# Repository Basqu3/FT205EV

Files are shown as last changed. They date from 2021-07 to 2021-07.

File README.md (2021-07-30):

# **FT205EV**

### Introductory Information:
	The FT205EV Sensor is an ultrasonic wind sensor. It utilizes known properties of sound to measure wind speed,
	wind direction in relation to the onboard compass, and temperature. This project provides a method to mount the sensor, PCB and required external battery on a DJI Inspire. 
	File List:
	PCB (not including Arduino, Micro-SD card holder or Micro-SD card)
	STL files for 3D printing (PLA)
	.INO file for Arduino

	The PCB .zip file folder is an EasyEDA format. It contains all required files, and a BOM parts list. 
		Some soldering skills are required to assemble the PCB. Note that the led-resistor combos (POWER and DATA) are optional.
		The POWER area can remain empty; DATA requires a solder bridge over both resistor and led footprints. 

	The STL 3D printing files are optimized for a 2S 7.4V LiPo Battery. The sensor mount screws onto the sensor; and twists into the Inspire Camera lock. 
		The enclosure box hooks on the thorn of the gimble, and clicks into place. 

	The .INO file needs to be uploaded to the Arduino before use with the sensor. It utilizes <SPI.h>, <SD.h>, <Wire.h>, and "RTClib.h" libraries. 

### Sensor Overview:
	The FT205EV sensor requires a DC voltage across the range of 6-30 V. The PCB will handle voltage between 6-8V. 
	If a different power source (not the 7.4V LiPo) is desired, voltage regulation needs to be included. 
	The Sensor uses Serial ASCII communication. It has 3 protocol options: RS422, RS485 and UART. This system utilizes UART. 
	Any connection to a pc can be done with the included RS485 cable. The PC will require a serial interface. This project recommends TeraTerm. 
	TeraTerm requires some familiarity to serial communications to use. Power the RS485 cable with a benchtop power supply (within 6-30V) and plug the USB into the PC. 
	Open TeraTerm and select the USB COM port in the serial dropdown. The Sensor requires CR+LF line endings so open SETUP>TERMINAL in the TeraTerm window. Change the New-Line      options from CR to CR+LF. 
	Optionally check the Local Echo box to see user input. Before any communications are made; the sensor needs to be set into RS485 mode and the continuous update turned off. Do that using these commands:
		$01,CUD*//  
		$01,CI8*//
	After these commands are entered; the sensor should be able to communicate with the PC. Either open the ACU-VIS included software or send commands through TeraTerm to ensure connection. 
	Check the Sensor User Manual to see full list of commands.

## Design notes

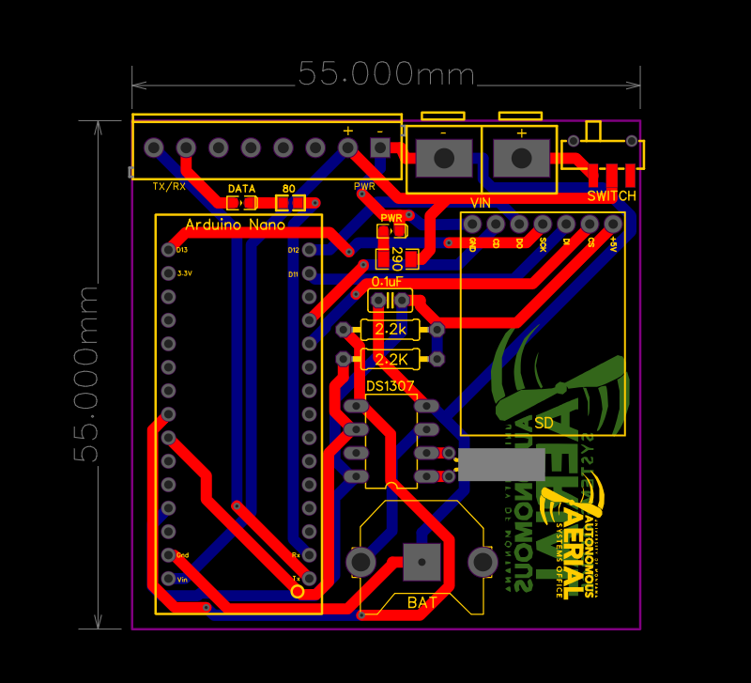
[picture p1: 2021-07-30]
PCB.png

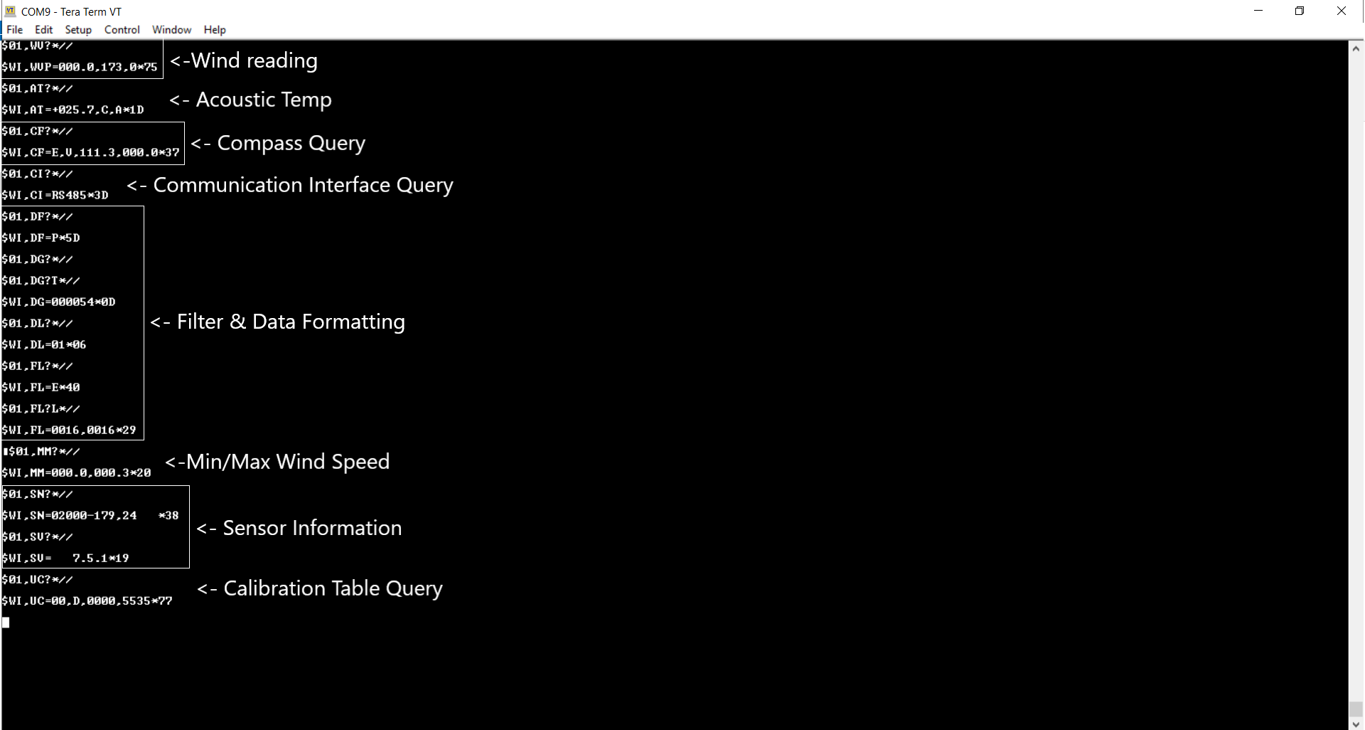
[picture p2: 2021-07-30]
TeraTermExampleLabeled.png

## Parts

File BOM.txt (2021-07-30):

1 FT205EV + requisite cables
1 Sensor Mount (3D Print)
1 Enclosure Box (3D Print)
1 2S LiPo Battery (7.4V)
1 PCB:
	1 Arduino Nano
	1 Sparkfun Level-shifting Micro-sd board   https://www.sparkfun.com/products/13743
	1 Slide Switch   https://www.digikey.com/en/products/detail/c-k/JS202011JCQN/6137630
	1 Capacitor      https://www.digikey.com/en/products/detail/vishay-bc-components/K103K15X7RF5UL2/8557356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
	1 CR1220-THM     https://www.keyelco.com/product.cfm/Thru-Hole-Mount/3001/product_id/778
	1 DS1307         https://www.digikey.com/en/products/detail/maxim-integrated/DS1307%2B/956883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
	1 Crystal        https://www.digikey.com/en/products/detail/wurth-electronics-inc/830025159/13979561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
	2 2.2K Ohm Resistors   Through-hole 
	1 80 Ohm Resistor Surface mount
	1 290 Ohm Resistor Surface mount
	2 Surface mount LEDs (blue and red)
	1 Power-in of user choice. Through-hole mount
	1 Screw terminal 8pc https://www.digikey.com/en/products/detail/cui-devices/TB006-508-08BE/10064121

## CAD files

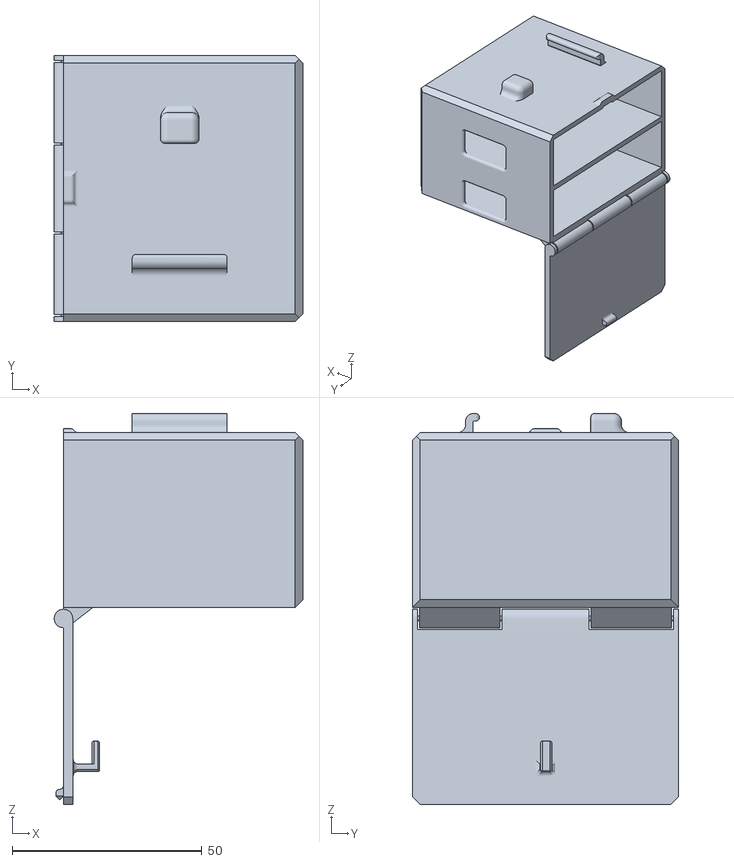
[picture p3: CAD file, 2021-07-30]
EnclosureBox.stl
65.4 x 70.0 x 102.9

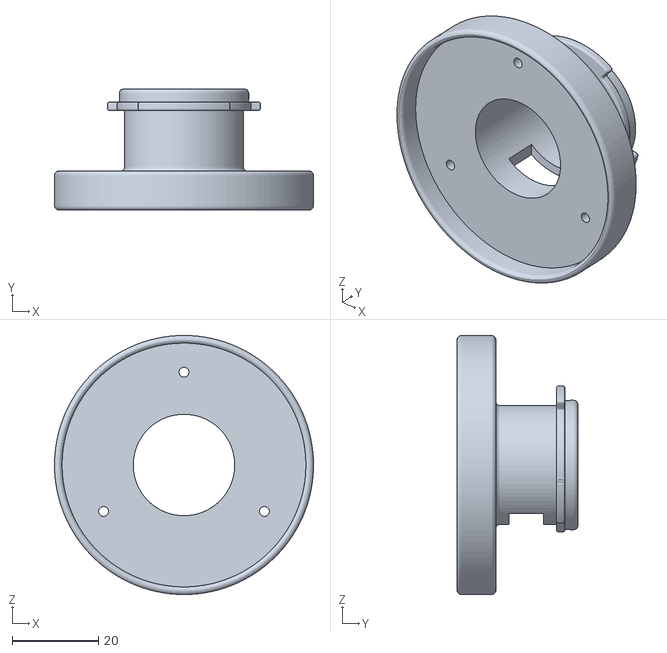
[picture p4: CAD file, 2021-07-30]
SensorMount.stl
60.0 x 28.0 x 60.0

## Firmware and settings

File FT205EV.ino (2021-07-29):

/*
  VCC -> 5V
  GND -> Gnd
  CS -> 8
  DI -> 11
  SCK -> 13
  DO ->12
  CD -> 9
*/

#include <SPI.h>
#include <SD.h>
#include <Wire.h>
#include "RTClib.h"

RTC_DS1307 rtc;
char windSpeed[11] = {'$','0','1','W','V','?','*','/','/','\r','\n'};
char temp[11] = {'$','0','1','A','T','?','*','/','/','\r','\n'};
String reply;
Sd2Card card;
const int chipSelect = 8;
char fileName[] = "T.txt"; //All caps required
void setup() {
  Serial.begin(9600);
  // Open serial communications and wait for port to open:
  while (!Serial);
  // wait for Serial Monitor to connect. Needed for native USB port boards only:
  if (! rtc.begin()) {
    Serial.println("Couldn't find RTC");
    while (1);
  }
  if (! rtc.isrunning()) {
    Serial.println("RTC is NOT running!");
    // following line sets the RTC to the date & time this sketch was compiled
    rtc.adjust(DateTime(F(__DATE__), F(__TIME__)));
    // This line sets the RTC with an explicit date & time, for example to set
    // January 21, 2014 at 3am you would call:
    // rtc.adjust(DateTime(2014, 1, 21, 3, 0, 0));
  }

  Serial.print("Initializing SD card...");
  //pinMode(10,OUTPUT);
  //digitalWrite(9,HIGH);
  //pinMode(8,OUTPUT);
  //digitalWrite(8,HIGH);

  if (!SD.begin(SPI_HALF_SPEED, chipSelect)) {
    pinMode(13,INPUT);

    Serial.println("initialization failed. Things to check:");

    Serial.println("1. is a card inserted?");

    Serial.println("2. is your sodering good");

    Serial.println("3. did you change the chipSelect pin to match your shield or module?");

    Serial.println("Note: press reset or reopen this serial monitor after fixing your issue!");

    while (1);

  }
  pinMode(13,OUTPUT);
  Serial.println("initialization done.");
}

void loop() {
  pinMode(10,OUTPUT);

  // open the file. note that only one file can be open at a time,

  // so you have to close this one before opening another.

  File dataFile = SD.open(fileName, FILE_WRITE);


  // if the file is available, write to it:

  if (dataFile) {
    pinMode(13,INPUT);
    pinMode(13,OUTPUT);
    DateTime now = rtc.now();
    dataFile.print(now.year(), DEC);
    dataFile.print('/');
    dataFile.print(now.month(), DEC);
    dataFile.print('/');
    dataFile.print(now.day(), DEC);
    dataFile.print(' ');
    dataFile.print(now.hour() - 7, DEC);
    dataFile.print(':');
    dataFile.print(now.minute(), DEC);
    dataFile.print(':');
    dataFile.print(now.second(), DEC);
    dataFile.print(' ');
    
    Serial.print(windSpeed);
    if (Serial.available()) {
      reply = Serial.readStringUntil("\n");  //reads reply from sensor until EOL symbol. Type=String
      dataFile.print(reply);
    }
    
    dataFile.print(' ');
    
    Serial.print(temp);
    if (Serial.available()) {
      reply = Serial.readStringUntil("\n");  //reads reply from sensor until EOL symbol. Type=String
      dataFile.print(reply);
    }
    
    dataFile.println();
    dataFile.close();
  }

  // if the file isn't open, pop up an error:

  else {

    pinMode(13,OUTPUT);

  }
  delay(3000);
}
